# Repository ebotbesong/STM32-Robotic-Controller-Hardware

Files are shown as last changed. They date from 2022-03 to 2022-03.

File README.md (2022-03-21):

# STM32 Robotic Controller Hardware
This project introduces the design of a PCB board layout for robotics applications. The microcontroller used in the board design is the STM32F103C8T6. The STM32F103C8T6 is a medium density performance line ARM Cortex-M3 32bit microcontroller in the 48 pin LQFP package. It incorporates high performance RISC core with up to 72MHz operating frequency, high speed embedded memories, extensive range of enhanced I/Os and peripherals connected buses.

The designed board can be use as an alternative to the well known and documented Arduino and raspberry pie hardware. Also, the provided design can be modify to add more memory if needed. This however increases the complexity of the hardware.

## Isometric view
The MicroUSB is used but this can be change to USB type-C which is becoming the de facto standard nowadays.

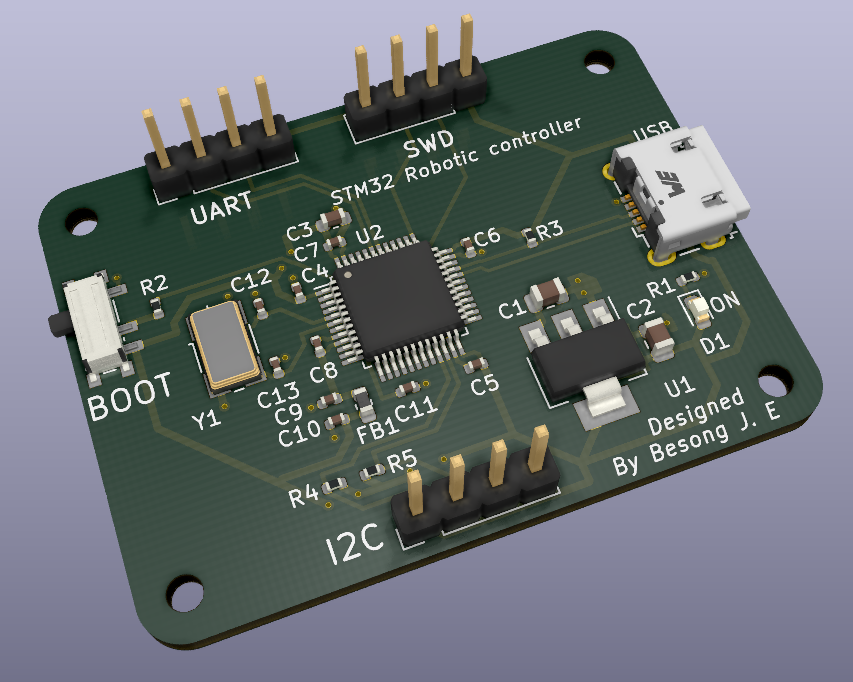
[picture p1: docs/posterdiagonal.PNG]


 ## Top view
 There is provision for I2C and UART connector in the design. Therefore both the I2C and UART bus lines can be used for control interfaces.

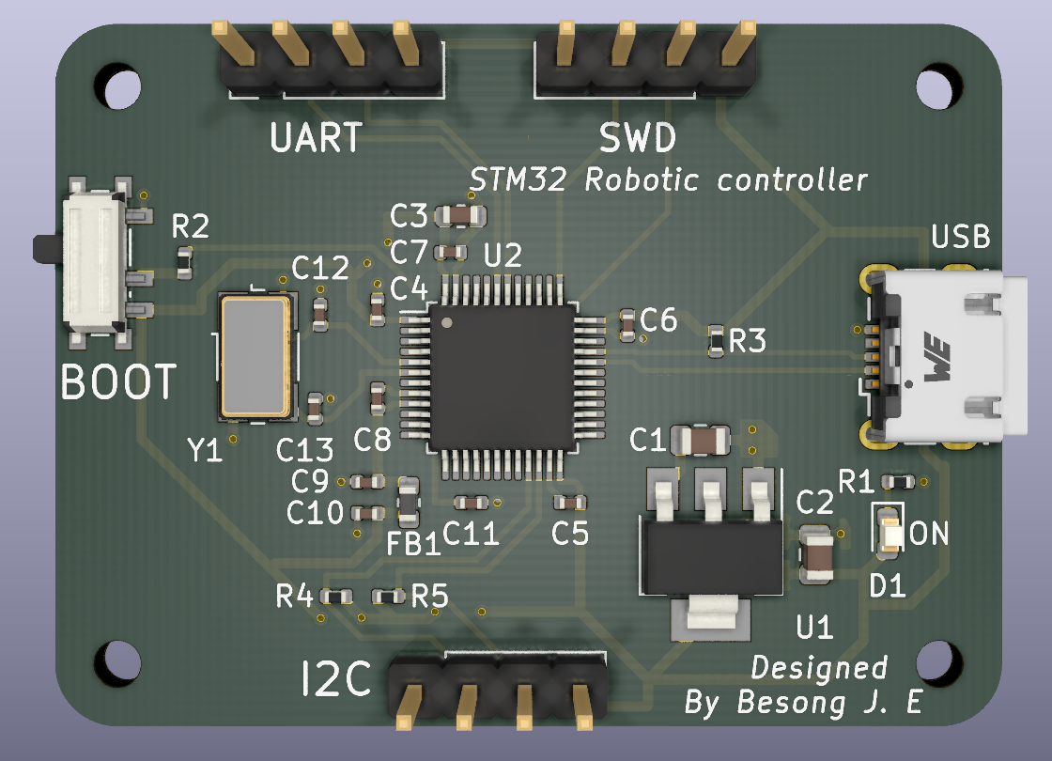
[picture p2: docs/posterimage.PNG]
 

## The PCB layout
The PCB layout was done using the KICAD EDA version 5.61 and the design is opensource. All design files are provided for download and can be found in the folder "docs" of the main repository shown above. Advanced version of the KICAD EDA can also be used to open the design files.

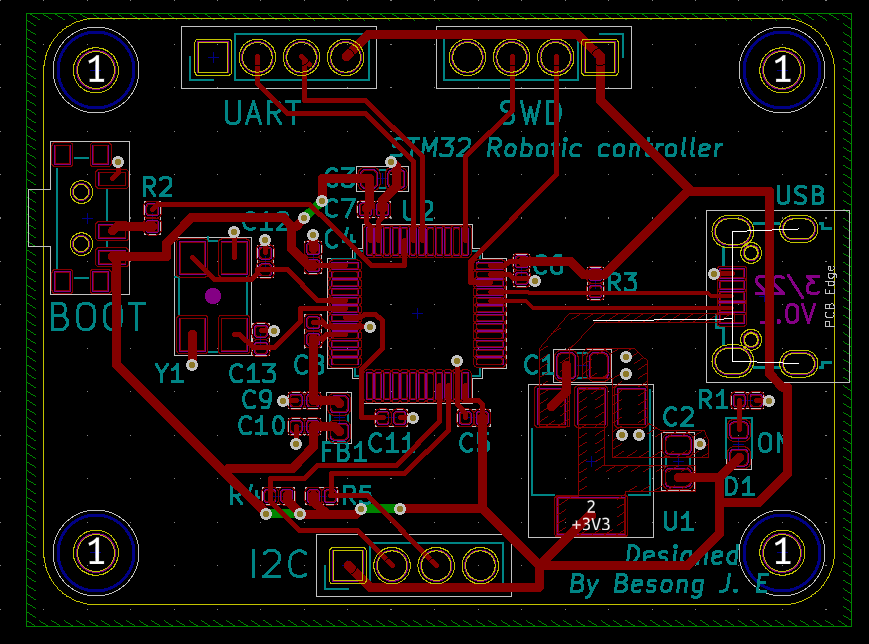
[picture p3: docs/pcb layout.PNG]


The project website is  https://ebotbesong.github.io/STM32-Robotic-Controller-Hardware/

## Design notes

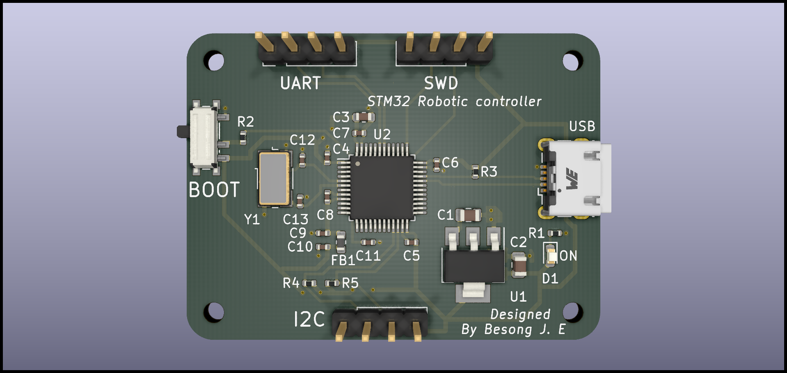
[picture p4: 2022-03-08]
PCB/STM32-project.png

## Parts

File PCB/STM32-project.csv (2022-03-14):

Id | Designator | Package | Quantity | Designation | Supplier and ref
1 | J1 | USB_Micro-B_Wuerth_629105150521 | 1 | USB_B_Micro
2 | SW1 | SW_SPDT_PCM12 | 1 | SW_SPDT
3 | H4,H3,H2,H1 | MountingHole_2.2mm_M2 | 4 | MountingHole
4 | Y1 | Crystal_SMD_0603-4Pin_6.0x3.5mm | 1 | 16MHz
5 | U2 | LQFP-48_7x7mm_P0.5mm | 1 | STM32F103C8T6
6 | U1 | SOT-223-3_TabPin2 | 1 | AMS1117-3.3
7 | R5,R4,R3,R1 | R_0402_1005Metric | 4 | 1k5
8 | R2 | R_0402_1005Metric | 1 | 10k
9 | J4,J3,J2 | PinHeader_1x04_P2.54mm_Vertical | 3 | Conn_01x04_Male
10 | FB1 | L_0603_1608Metric | 1 | Ferrite_Bead
11 | D1 | LED_0603_1608Metric | 1 | RED
12 | C13,C12 | C_0402_1005Metric | 2 | 10p
13 | C11,C7,C6,C5,C4 | C_0402_1005Metric | 5 | 100n
14 | C10,C9 | C_0402_1005Metric | 2 | 1u
15 | C8 | C_0402_1005Metric | 1 | 10u
16 | C3 | C_0603_1608Metric | 1 | 10u
17 | C2,C1 | C_0805_2012Metric | 2 | 22u

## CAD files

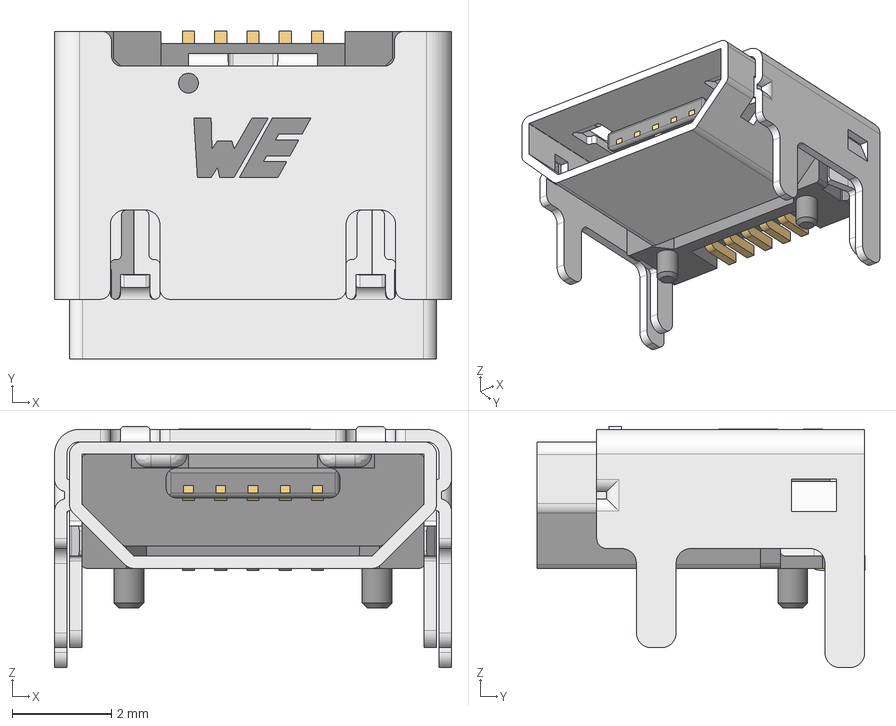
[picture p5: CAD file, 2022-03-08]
PCB/Wurth_-_629105150521.step
8.00 x 6.60 x 4.86 mm
629105150521_Pin1 x 4
629105150521_Housing
629105150521_Pin2
629105150521_Shielding
629105150521_Shielding2
logo

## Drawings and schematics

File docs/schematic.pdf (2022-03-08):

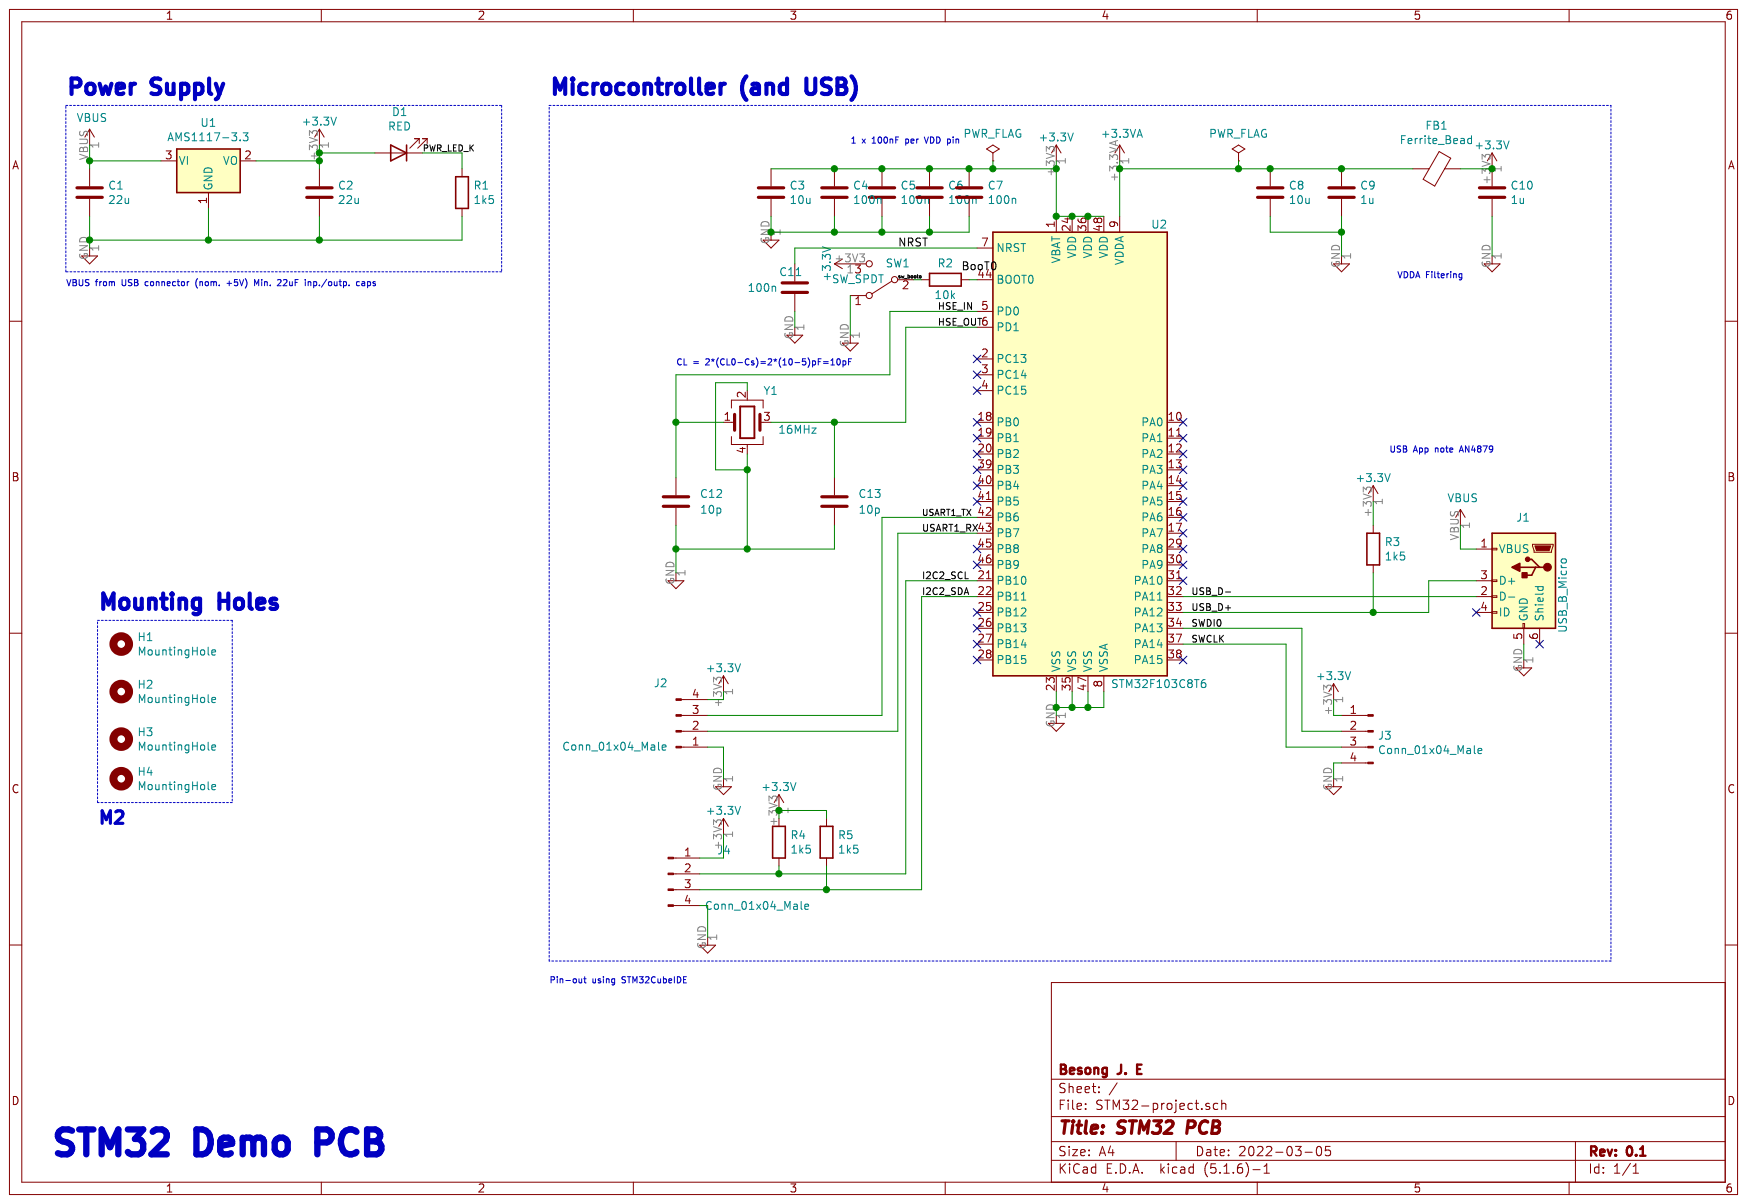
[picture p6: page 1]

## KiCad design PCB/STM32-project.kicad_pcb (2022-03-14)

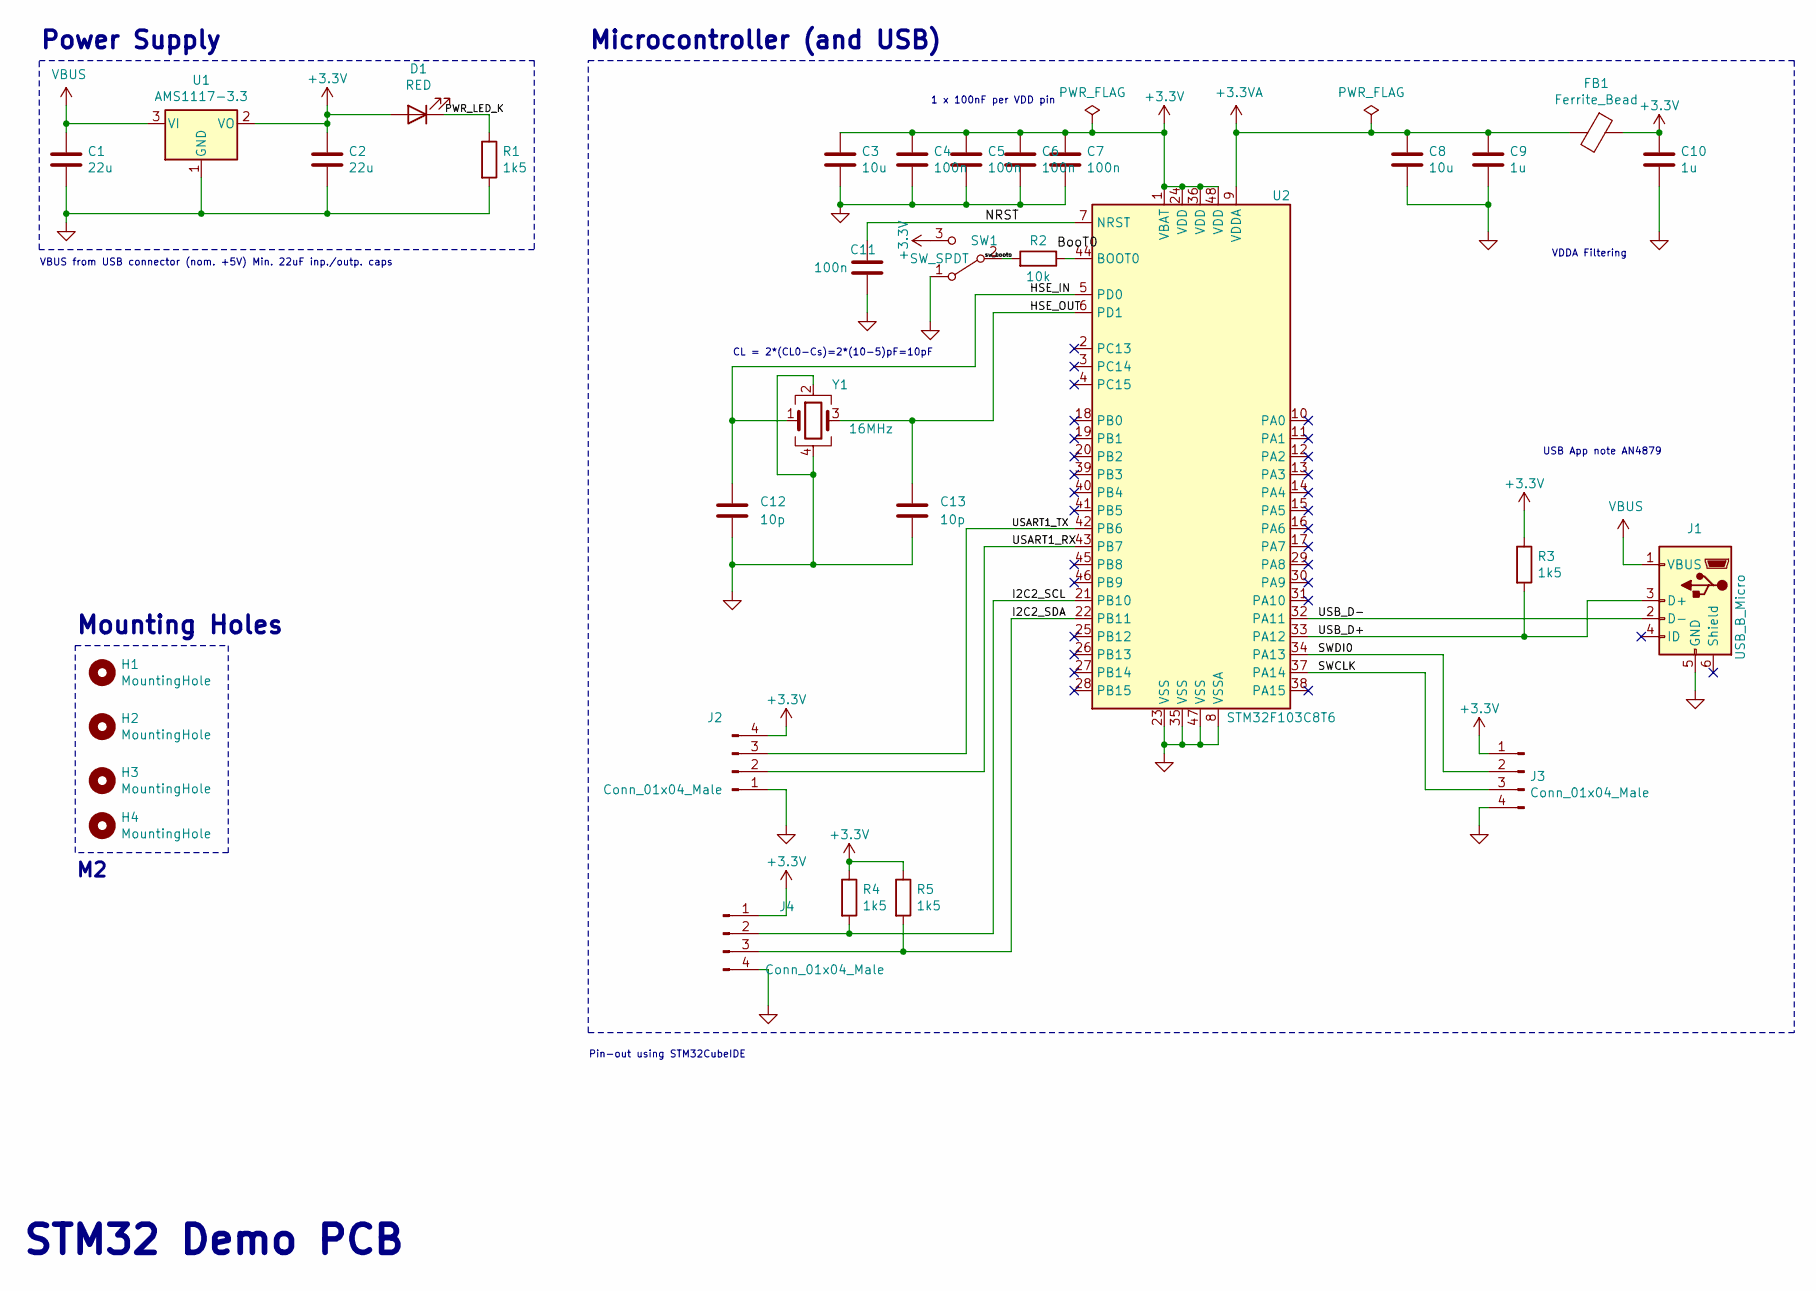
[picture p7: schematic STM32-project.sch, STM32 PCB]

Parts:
C1, C2: 22u; C_0805_2012Metric
C3: 10u; C_0603_1608Metric
C4, C5, C6, C7, C11: 100n; C_0402_1005Metric
C8: 10u; C_0402_1005Metric
C9, C10: 1u; C_0402_1005Metric
C12, C13: 10p; C_0402_1005Metric
D1: RED; LED_0603_1608Metric
FB1: Ferrite_Bead; L_0603_1608Metric
H1, H2, H3, H4: MountingHole; MountingHole_2.2mm_M2
J1: USB_B_Micro; USB_Micro-B_Wuerth_629105150521
J2, J3, J4: Conn_01x04_Male; PinHeader_1x04_P2.54mm_Vertical
R1, R3, R4, R5: 1k5; R_0402_1005Metric
R2: 10k; R_0402_1005Metric
SW1: SW_SPDT; SW_SPDT_PCM12
U1: AMS1117-3.3; SOT-223-3_TabPin2
U2: STM32F103C8T6; LQFP-48_7x7mm_P0.5mm
Y1: 16MHz; Crystal_SMD_0603-4Pin_6.0x3.5mm

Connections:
+3.3VA: C8.1, C9.1, FB1.2, U2.9 (VDDA)
+3V3: C2.1, C3.1, C4.1, C5.1, C6.1, C7.1, C10.1, D1.2 (A), FB1.1, J2.4, J3.1, J4.1, R3.1, R4.1, R5.1, SW1.3 (C), U1.2 (VO), U2.1 (VBAT), U2.24 (VDD), U2.36 (VDD), U2.48 (VDD)
/HSE_IN: C12.1, U2.5 (PD0), Y1.1
/HSE_OUT: C13.1, U2.6 (PD1), Y1.3
/I2C2_SCL: J4.2, R4.2, U2.21 (PB10)
/I2C2_SDA: J4.3, R5.2, U2.22 (PB11)
/NRST: C11.1, U2.7 (NRST)
/PWR_LED_K: D1.1 (K), R1.1
/SWCLK: J3.3, U2.37 (PA14)
/SWDI0: J3.2, U2.34 (PA13)
/USART1_RX: J2.2, U2.43 (PB7)
/USART1_TX: J2.3, U2.42 (PB6)
/USB_D+: J1.3 (D+), R3.2, U2.33 (PA12)
/USB_D-: J1.2 (D-), U2.32 (PA11)
GND: C1.2, C2.2, C3.2, C4.2, C5.2, C6.2, C7.2, C8.2, C9.2, C10.2, C11.2, C12.2, C13.2, J1.5 (GND), J2.1, J3.4, J4.4, R1.2, SW1.1 (A), U1.1 (GND), U2.8 (VSSA), U2.23 (VSS), U2.35 (VSS), U2.47 (VSS), Y1.2, Y1.4
unnamed: R2.1, U2.44 (BOOT0)
unnamed: R2.2, SW1.2 (B)
VBUS: C1.1, J1.1 (VBUS), U1.3 (VI)

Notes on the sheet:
Microcontroller (and USB)
STM32 Demo PCB
1 x 100nF per VDD pin
CL = 2*(CL0-Cs)=2*(10-5)pF=10pF
USB App note AN4879
VDDA Filtering
Pin-out using STM32CubeIDE
VBUS from USB connector (nom. +5V) Min. 22uF inp./outp. caps
Power Supply
Mounting Holes

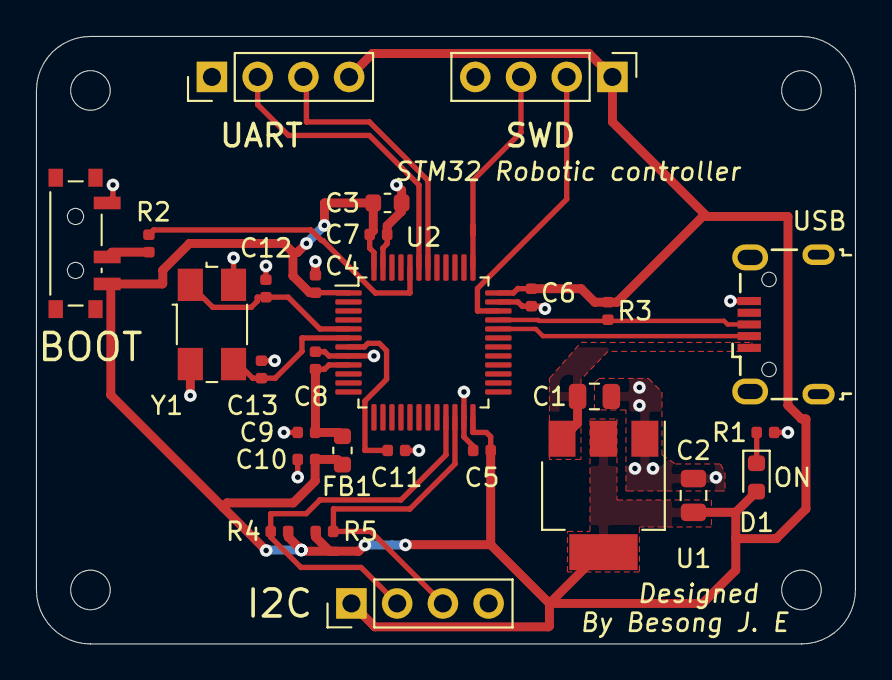
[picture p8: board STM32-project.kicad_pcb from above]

Board: 2 copper layers, 45.5 x 33.8 mm, 32 parts (0 on the bottom side), 18 nets.

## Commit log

2022-03-08 :star: initial commit
    [STM32-project-B_Cu.gbr, STM32-project-B_Mask.gbr, STM32-project-B_Paste.gbr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]
2022-03-08 modefied the main pcb board. The power tracks
    [STM32-project.kicad_pcb]
2022-03-08 created the image for pcb layout
2022-03-14 Added BOM file
    [STM32-project.csv, STM32-project.kicad_pcb]
